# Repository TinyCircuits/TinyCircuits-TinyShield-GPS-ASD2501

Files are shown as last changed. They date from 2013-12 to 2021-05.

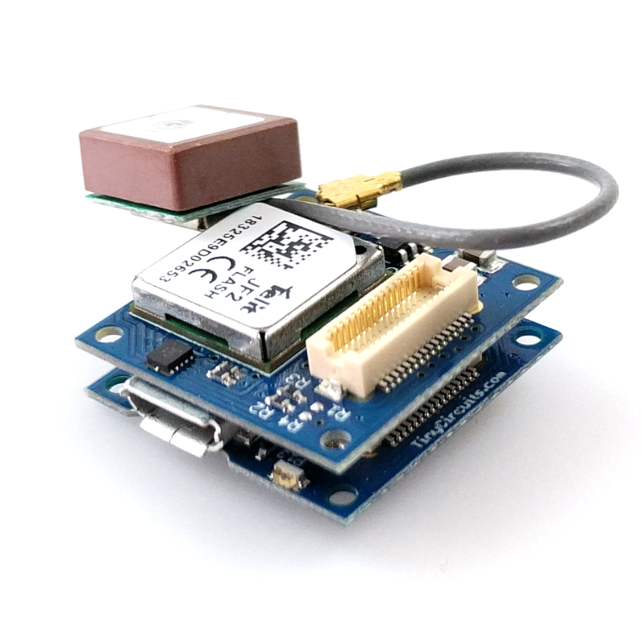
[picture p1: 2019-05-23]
images/ASD2501-R-Tutorial-Image-03.jpg

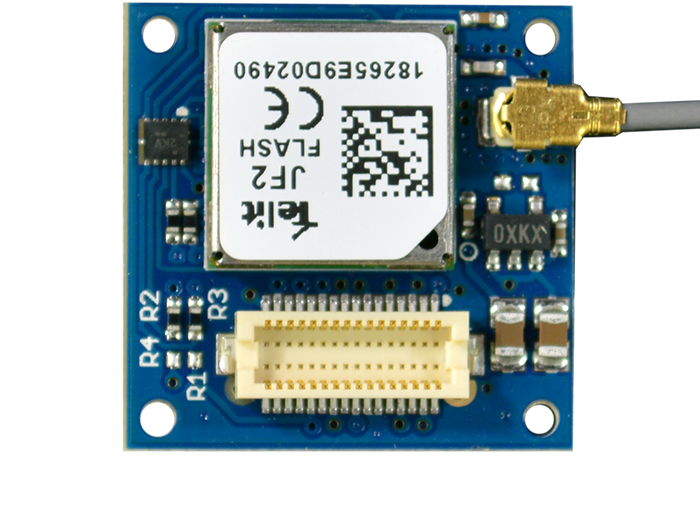
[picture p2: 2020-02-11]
images/ASD2501-R-Tutorial-Image-01.png

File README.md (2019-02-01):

# TinyCircuits TinyShield GPS Board
# ASD2501 Rev4

The design files are located under design_files/ for the TinyCircuits ASD2501 Rev 4 PCB.  This is a TinyShield board that has a GPS module, local power supply, antenna and level shifters to receive GPS data.

Format is in Cadsoft Eagle format - Eagle version 6.2 was used for the original design.

For more infomation on this, check out the product page at TinyCircuits.com:  https://tinycircuits.com/collections/sensors/products/gps-tinyshield

#License:

Design by TinyCircuits.
All design files are released under the Creative Commons Attribution Share-Alike 3.0 License, see the following link for details: http://creativecommons.org/licenses/by-sa/3.0

All text above must be included in any redistribution or derived design

This project uses designs and concepts developed as part of the Arduino project and the LilyPad project.  The TinyCircuits design files themselves (schematics, PCB and libraries) are not directly derived from these works' design files and have been created new, however the concepts and basic architecture behind the TinyDuino and TinyLily products are derived and we thank the hard work of the organizations below for their contributions to open-source hardware:
  
Original Arduino Uno Design by Team Arduino

LilyPad Arduino Design by Leah Buechley and Sparkfun Electronics

Please support the open-source hardware community

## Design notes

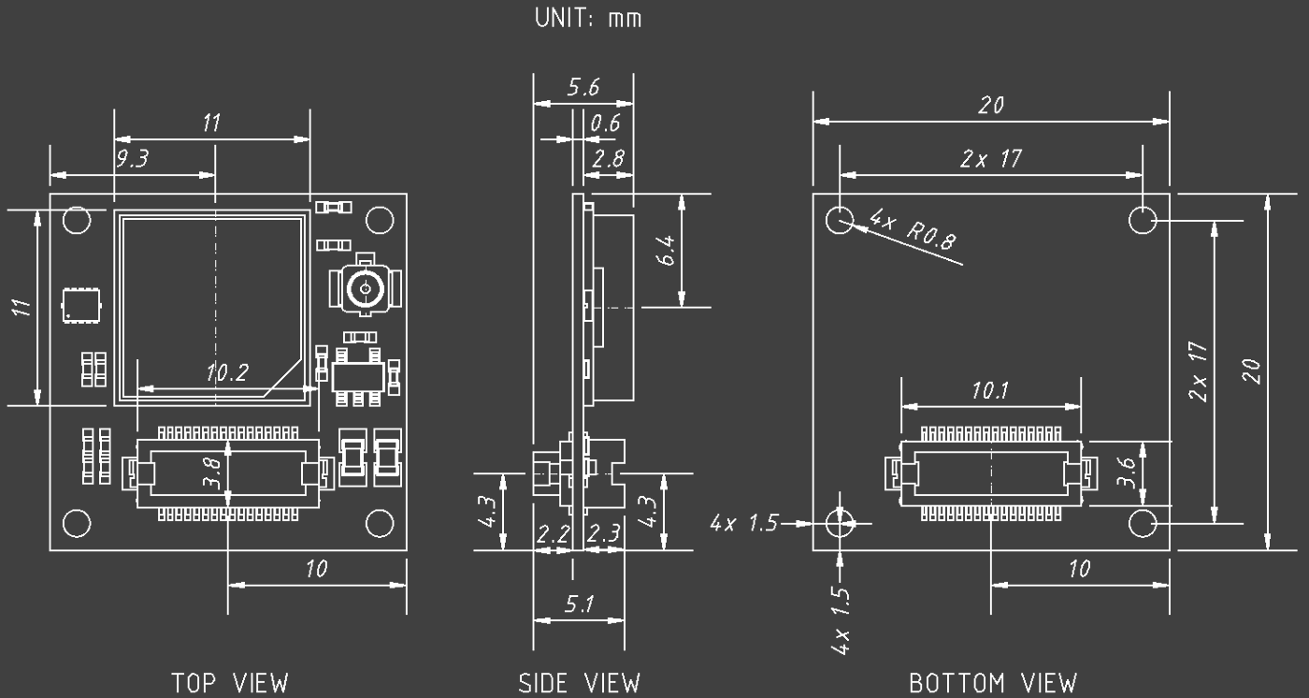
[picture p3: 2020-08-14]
cad/TinyShield_GPS_ASD2501_REV4-DETAILED_DRAWING_COMPACT-PNG.png

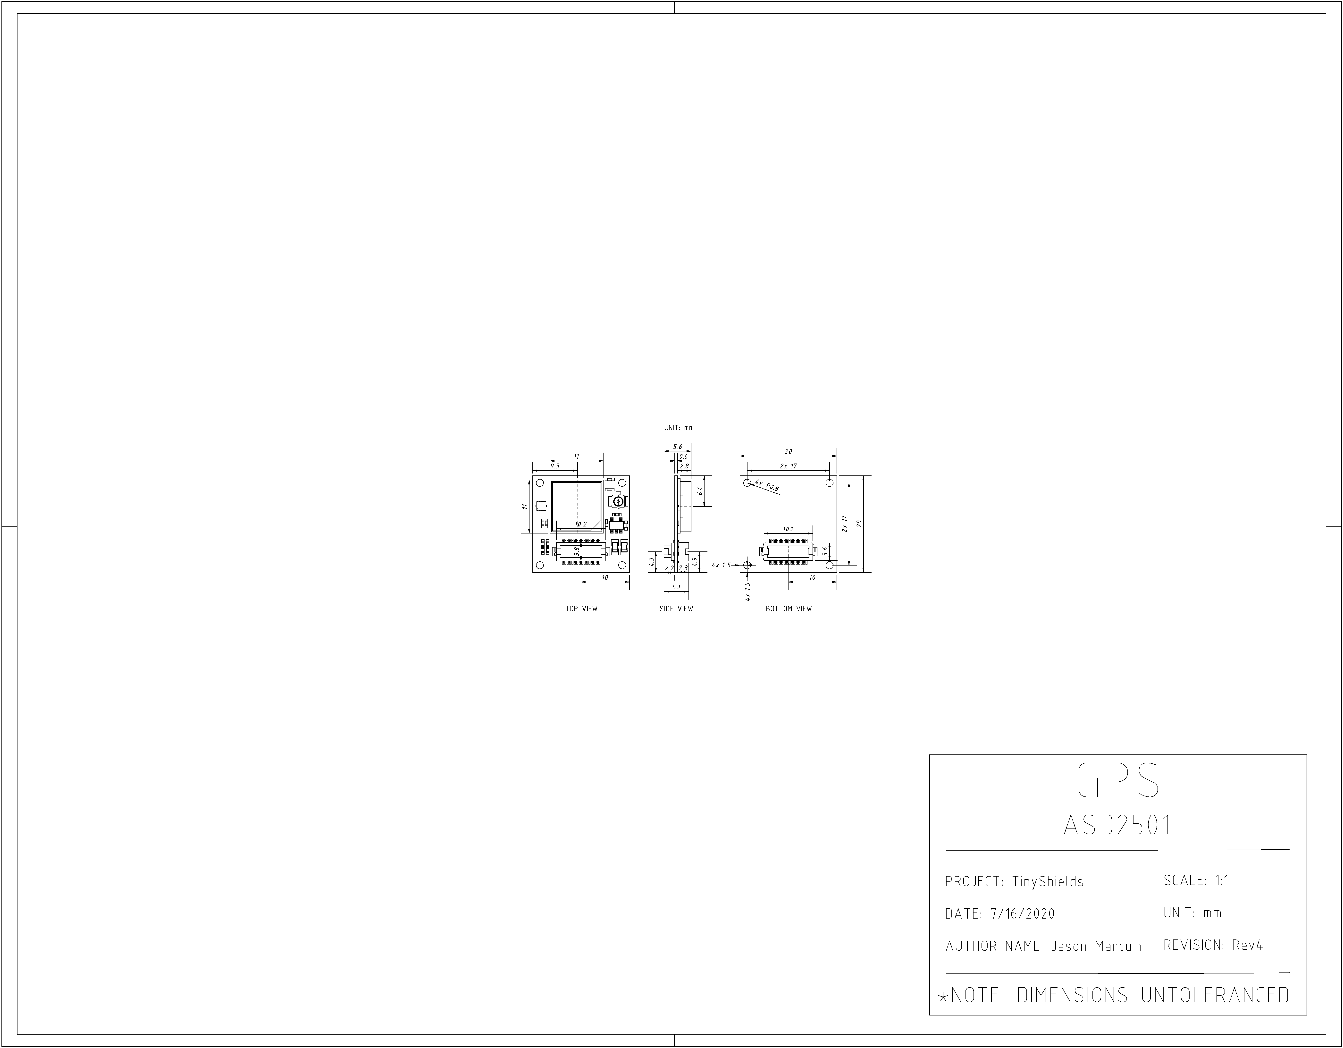
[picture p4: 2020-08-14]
cad/TinyShield_GPS_ASD2501_REV4-DETAILED_DRAWING-PNG.png

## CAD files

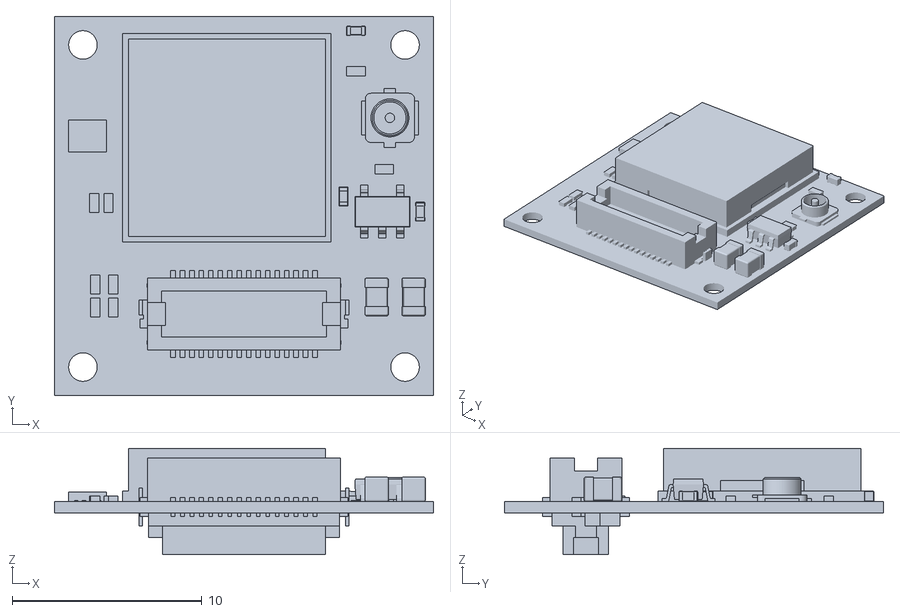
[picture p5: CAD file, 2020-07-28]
cad/TinyShield_GPS_ASD2501_REV4-STL.stl
20.0 x 20.0 x 5.60

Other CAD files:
cad/TinyShield_GPS_ASD2501_REV4-DETAILED_DRAWING-DXF.dxf

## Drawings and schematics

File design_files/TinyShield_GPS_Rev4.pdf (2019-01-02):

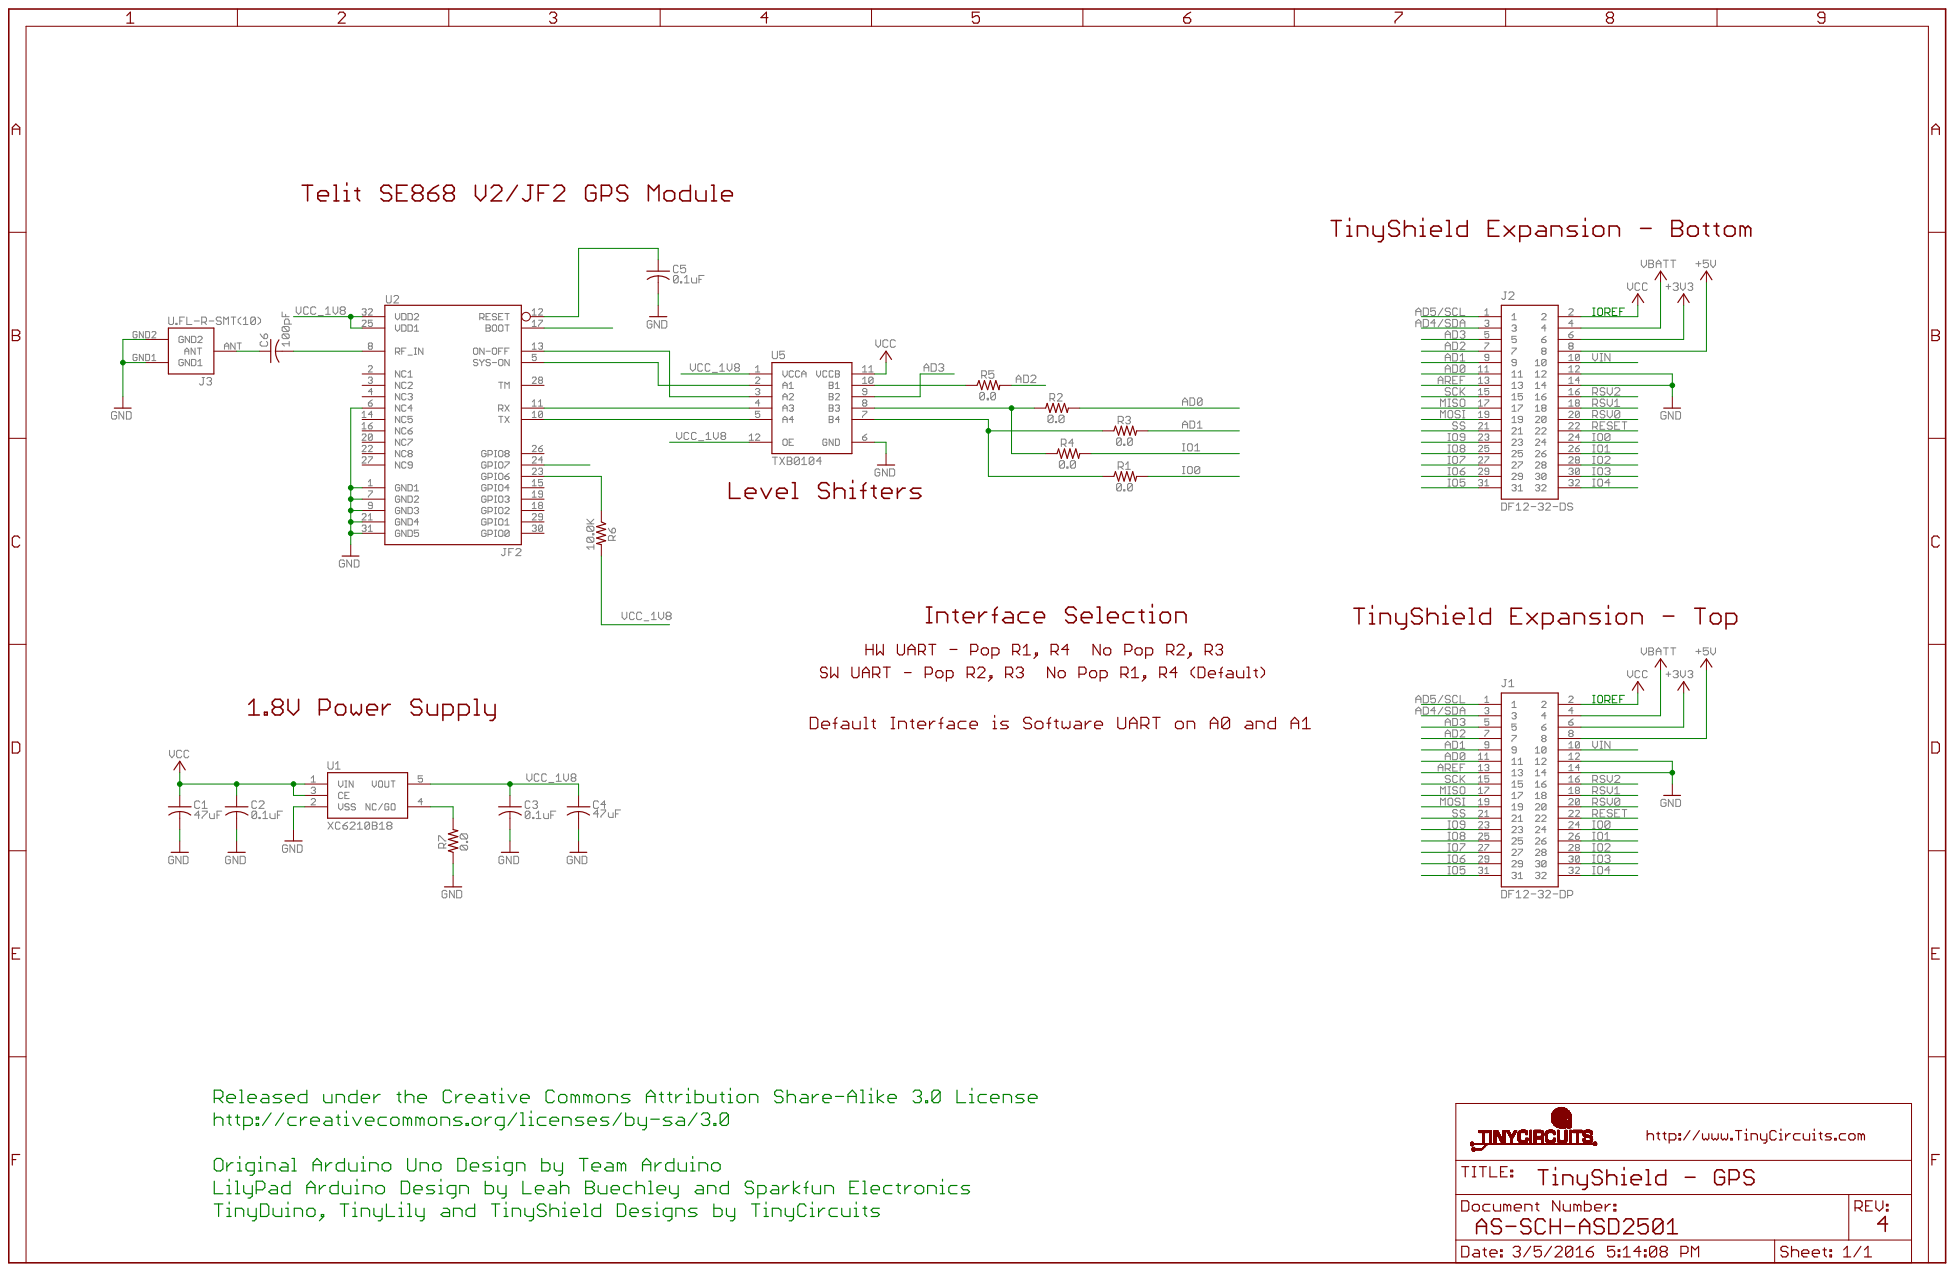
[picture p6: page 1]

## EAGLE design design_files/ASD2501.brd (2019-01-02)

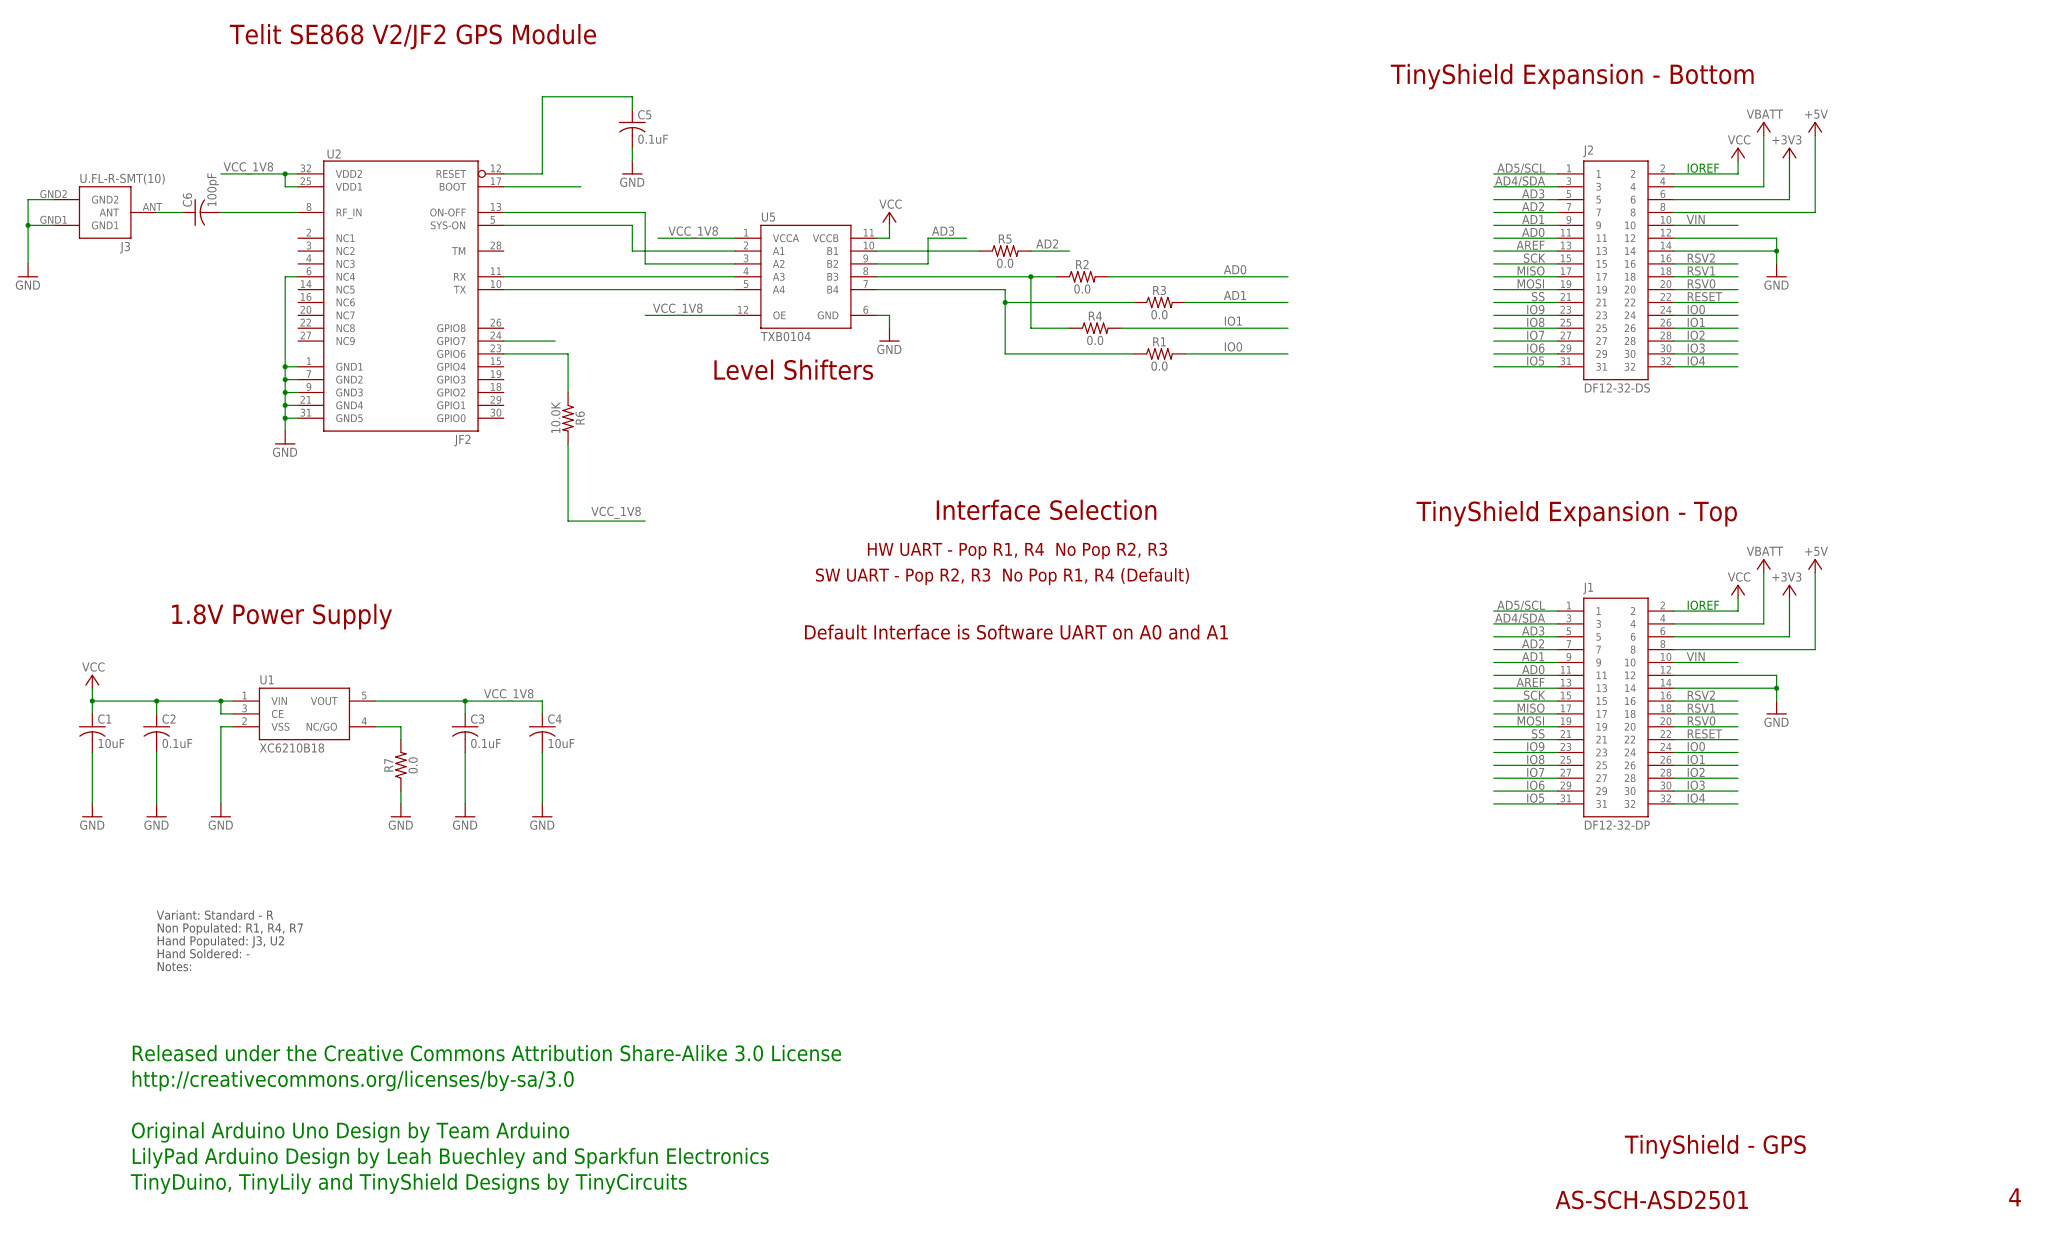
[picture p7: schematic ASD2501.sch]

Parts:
C1, C4: 10uF; C0805; PARTNO AS-ITM-00045
C2, C3, C5: 0.1uF; C0402; PARTNO AS-ITM-00008
C6: 100pF; 0402; PARTNO AS-ITM-00148
J1: DF12-32-DP; PARTNO AS-ITM-00015
J2: DF12-32-DS; PARTNO AS-ITM-00012
J3: U.FL-R-SMT(10)
R1, R2, R3, R4: 0.0; 0402
R5, R7: 0.0; 0402; PARTNO AS-ITM-00076
R6: 10.0K; 0402
U1: XC6210B18; SOT-25; PARTNO AS-ITM-00075
U2: JF2
U5: TXB0104; UQFN-12

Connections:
+3V3: J1.6, J2.6
+5V: J1.8, J2.8
AD0: J1.11, J2.11, R2.2
AD1: J1.9, J2.9, R3.2
AD2: J1.7, J2.7, R5.2
AD3: J1.5, J2.5, U5.9 (B2)
AD4/SDA: J1.3, J2.3
AD5/SCL: J1.1, J2.1
AREF: J1.13, J2.13
GND: C1.2, C2.2, C3.2, C4.2, C5.2, J1.12, J1.14, J2.12, J2.14, J3.GND1, J3.GND2, R7.1, U1.2 (VSS), U2.1 (GND1), U2.6 (NC4), U2.7 (GND2), U2.9 (GND3), U2.21 (GND4), U2.31 (GND5), U5.6 (GND)
IO0: J1.24, J2.24, R1.2
IO1: J1.26, J2.26, R4.2
IO2: J1.28, J2.28
IO3: J1.30, J2.30
IO4: J1.32, J2.32
IO5: J1.31, J2.31
IO6: J1.29, J2.29
IO7: J1.27, J2.27
IO8: J1.25, J2.25
IO9: J1.23, J2.23
MISO: J1.17, J2.17
MOSI: J1.19, J2.19
unnamed: C6.1, J3.ANT
unnamed: R2.1, R4.1, U5.8 (B3)
unnamed: R1.1, R3.1, U5.7 (B4)
unnamed: U2.11 (RX), U5.4 (A3)
unnamed: R6.1, U2.23 (GPIO6)
unnamed: R7.2, U1.4 (NC/GO)
unnamed: U2.10 (TX), U5.5 (A4)
unnamed: C5.1, U2.12 (RESET)
unnamed: C6.2, U2.8 (RF_IN)
unnamed: U2.13 (ON-OFF), U5.3 (A2)
unnamed: U2.5 (SYS-ON), U5.2 (A1)
unnamed: R5.1, U5.10 (B1)
RESET: J1.22, J2.22
RSV0: J1.20, J2.20
RSV1: J1.18, J2.18
RSV2: J1.16, J2.16
SCK: J1.15, J2.15
SS: J1.21, J2.21
VBATT: J1.4, J2.4
VCC: C1.1, C2.1, J1.2, J2.2, U1.1 (VIN), U1.3 (CE), U5.11 (VCCB)
VCC_1V8: C3.1, C4.1, R6.2, U1.5 (VOUT), U2.25 (VDD1), U2.32 (VDD2), U5.1 (VCCA), U5.12 (OE)
VIN: J1.10, J2.10

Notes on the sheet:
TinyShield Expansion - Bottom
TinyShield - GPS
AS-SCH-ASD2501
TinyShield Expansion - Top
IOREF
Released under the Creative Commons Attribution Share-Alike 3.0 License
http://creativecommons.org/licenses/by-sa/3.0
LilyPad Arduino Design by Leah Buechley and Sparkfun Electronics
TinyDuino, TinyLily and TinyShield Designs by TinyCircuits
Original Arduino Uno Design by Team Arduino
1.8V Power Supply
Telit SE868 V2/JF2 GPS Module
Level Shifters
Interface Selection
HW UART - Pop R1, R4 No Pop R2, R3
Default Interface is Software UART on A0 and A1
SW UART - Pop R2, R3 No Pop R1, R4 (Default)
Non Populated: R1, R4, R7
Hand Populated: J3, U2
Hand Soldered: -
Notes:
Variant: Standard - R

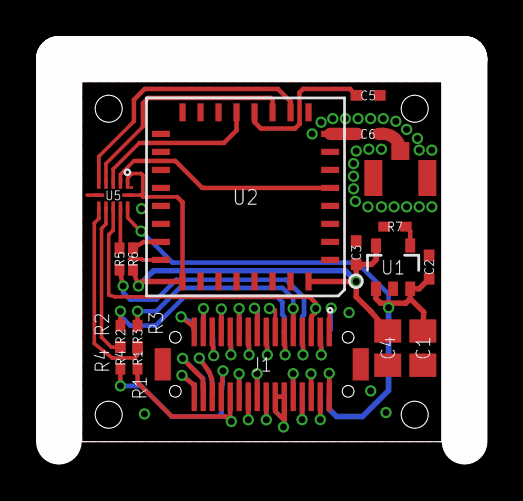
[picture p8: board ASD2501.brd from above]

Board: 2 copper layers, 20.0 x 20.0 mm, 20 parts (1 on the bottom side), 44 nets.

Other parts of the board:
U$1: DOCFIELD-TINYCIRCUITS-PCB

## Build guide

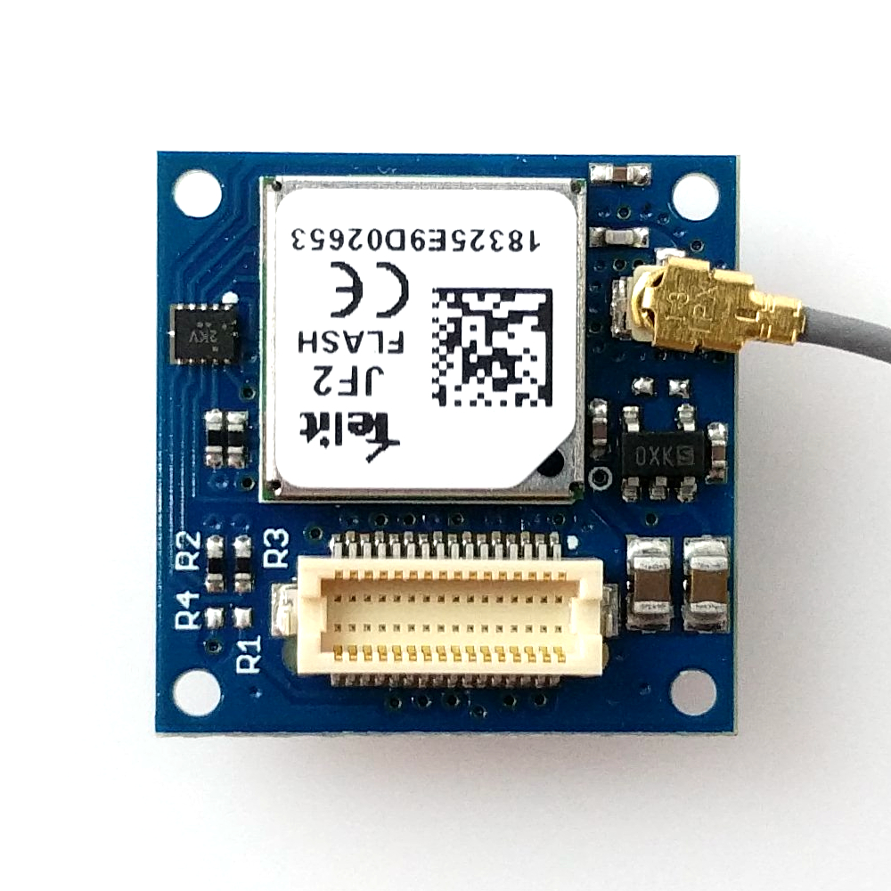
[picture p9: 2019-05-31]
images/ASD2501-R-Tutorial-Image-01.jpg

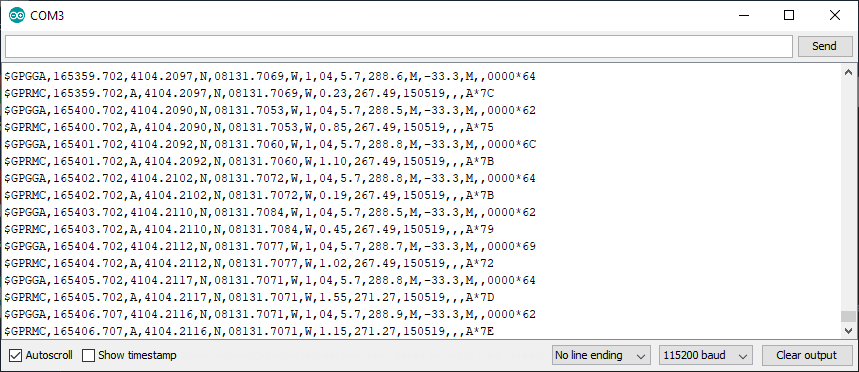
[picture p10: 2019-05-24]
images/ASD2501-Tutorial-Image-05.png

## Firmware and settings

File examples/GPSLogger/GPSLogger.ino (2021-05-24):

/*
  TinyCircuits GPS TinyShield Logging Example
  
  This example logs GPS NMEA sentences to an SD card. If it doesn't detect an SD
  card at startup, it will output data to the Serial Monitor.
  With the Telit SE868 V2 module with Glonass support, some messages come through
  as GN** sentences instead of GP**. These are changed back to GP** before logging
  so that they don't cause problems with programs like Google Earth.
  
  If you see bad data:
  - Make sure the baud rate in the Serial Monitor is the same you see set in the below 
    program for the SerialMonitorInterface - 115200
  - Some GPS modules shipped before 2018 shipped with 4800 baud instead of 9600. Try changing 
    this value in the top of the GPS.h file.

  Written 10 July 2018 By Ben Rose
  Modified 07 January 2019 By Hunter Hykes
   - This update added SoftwareSerialZero files modified for SAMD21 based boards like
     the TinyScreen+, TinyZero or Arduino Zero.
  Modified May 2021 to clarify comments

  https://TinyCircuits.com
*/

#include "GPS.h"
#include <SD.h>

#if defined (ARDUINO_ARCH_AVR)
#define SerialMonitorInterface Serial
#include <SoftwareSerial.h>
#elif defined(ARDUINO_ARCH_SAMD)
#define SerialMonitorInterface SerialUSB
#include "SoftwareSerialZero.h"
#endif

const int chipSelect = 10;
int cardPresent;

// The GPS connection is attached with a software serial port
SoftwareSerial softSerial(GPS_RXPin, GPS_TXPin);

#define Gps_serial softSerial

void setup()
{
  Gps_serial.begin(GPSBaud);
  SerialMonitorInterface.begin(115200);
  while (!SerialMonitorInterface && millis() < 5000); //On TinyScreen+, this will wait until the Serial Monitor is opened or until 5 seconds has passed

  gpsInitPins();
  delay(100);
  SerialMonitorInterface.print("Attempting to wake GPS module.. ");
  gpsOn();
  SerialMonitorInterface.println("done.");
  delay(200);

  //Enable and set interval or disable, per NMEA sentence type
  Gps_serial.print(gpsConfig(NMEA_GGA_SENTENCE, 1));
  Gps_serial.print(gpsConfig(NMEA_GLL_SENTENCE, 0));
  Gps_serial.print(gpsConfig(NMEA_GSA_SENTENCE, 0));
  Gps_serial.print(gpsConfig(NMEA_GSV_SENTENCE, 0));
  Gps_serial.print(gpsConfig(NMEA_RMC_SENTENCE, 1));
  Gps_serial.print(gpsConfig(NMEA_VTG_SENTENCE, 0));
  Gps_serial.print(gpsConfig(NMEA_GNS_SENTENCE, 0));

  SerialMonitorInterface.print("Initializing SD card...");

  // see if the card is present and can be initialized:
  if (SD.begin(chipSelect)) {
    SerialMonitorInterface.println("card initialized.");
    cardPresent = true;
  } else {
    SerialMonitorInterface.println("Card failed, or not present- continuing with serial output");
    cardPresent = false;
  }
}

void loop() {
  handleGPS();
}

char waitForCharacter() {
  while (!Gps_serial.available());
  return Gps_serial.read();
}

void handleGPS() {
  while (Gps_serial.read() != '$') {
    if(!Gps_serial.available()){
      return;
    }
  }
  int counter = 1;
  char c = 0;
  char buffer[100];
  buffer[0] = '$';
  c = waitForCharacter();
  while (c != '*') {
    buffer[counter++] = c;
    if(c=='$'){//new start
      counter=1;
    }
    c = waitForCharacter();
  }
  buffer[counter++] = c;
  buffer[counter++] = waitForCharacter();
  buffer[counter++] = waitForCharacter();
  buffer[counter++] = '\r';
  buffer[counter++] = '\n';
  buffer[counter] = '\0';

  buffer[1] = 'G';
  buffer[2] = 'P';

  gpsDoChecksum(buffer);

  if (cardPresent) {
    File dataFile = SD.open("gps.txt", FILE_WRITE);
    // if the file is available, write to it:
    if (dataFile) {
      dataFile.write(buffer, counter);
      dataFile.close();
    } else {
      SerialMonitorInterface.println("error opening gps.txt");
      cardPresent = false;
    }
  } else {
    SerialMonitorInterface.print((char *)buffer);
  }
}

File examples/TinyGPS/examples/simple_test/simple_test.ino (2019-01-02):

/* This sample code demonstrates the normal use of a TinyGPS object,
 * customised for the TinyCircuits GPS module.
*/


#include <TinyGPS.h>
#include "GPS.h"

TinyGPS gps;
char buf[32];

#if defined (ARDUINO_ARCH_AVR)
#define SerialMonitorInterface Serial
#include <SoftwareSerial.h>
#elif defined(ARDUINO_ARCH_SAMD)
#define SerialMonitorInterface SerialUSB
#include "SoftwareSerialZero.h"
#endif

// The GPS connection is attached with a software serial port
SoftwareSerial ss(GPS_RXPin, GPS_TXPin);


void setup()
{
  SerialMonitorInterface.begin(115200);
  ss.begin(GPSBaud);
  while (!SerialMonitorInterface && millis() < 5000); //On TinyScreen+/SAMD21 platform, this will wait until the Serial Monitor is opened or until 5 seconds has passed
  
  SerialMonitorInterface.print("Simple TinyGPS library v. "); SerialMonitorInterface.println(TinyGPS::library_version());
  SerialMonitorInterface.println("by Mikal Hart");
  SerialMonitorInterface.println();
  
  gpsInitPins();
  delay(100);
  SerialMonitorInterface.print("Attempting to wake GPS module.. ");
  gpsOn();
  SerialMonitorInterface.println("done.");
  delay(100);
  while (ss.available())ss.read();
}

void loop()
{
  bool newData = false;
  unsigned long chars;
  unsigned short sentences, failed;

  // For one second we parse GPS data and report some key values
  for (unsigned long start = millis(); millis() - start < 1000;)
  {
    while (ss.available())
    {
      char c = ss.read();
      // SerialMonitorInterface.write(c); // uncomment this line if you want to see the GPS data flowing
      if (gps.encode(c)) // Did a new valid sentence come in?
        newData = true;
    }
  }

  unsigned long age;
  if (newData)
  {
    float flat, flon;
    gps.f_get_position(&flat, &flon, &age);
    SerialMonitorInterface.print("LAT=");
    SerialMonitorInterface.print(flat == TinyGPS::GPS_INVALID_F_ANGLE ? 0.0 : flat, 6);
    SerialMonitorInterface.print(" LON=");
    SerialMonitorInterface.print(flon == TinyGPS::GPS_INVALID_F_ANGLE ? 0.0 : flon, 6);
    SerialMonitorInterface.print(" SAT=");
    SerialMonitorInterface.print(gps.satellites() == TinyGPS::GPS_INVALID_SATELLITES ? 0 : gps.satellites());
    SerialMonitorInterface.print(" PREC=");
    SerialMonitorInterface.print(gps.hdop() == TinyGPS::GPS_INVALID_HDOP ? 0 : gps.hdop());
    //GPS mode
    SerialMonitorInterface.print(" Constellations=");
    SerialMonitorInterface.print(flat == TinyGPS::GPS_INVALID_F_ANGLE ? 0 : gps.constellations());
  }

  //satellites in view
  uint32_t* satz = gps.trackedSatellites();
  uint8_t sat_count = 0;
  for(int i=0;i<24;i++)
  {
    if(satz[i] != 0)    //exclude zero SNR sats
    {
      sat_count++;
      byte strength = (satz[i]&0xFF)>>1;
      byte prn = satz[i]>>8;
      sprintf(buf, "PRN %d: ", prn);
      SerialMonitorInterface.print(buf);
      SerialMonitorInterface.print(strength);
      SerialMonitorInterface.println("dB");
    }
  }
  
  //date time
  int year;
  uint8_t month, day, hour, minutes, second, hundredths;
  gps.crack_datetime(&year, &month, &day, &hour, &minutes, &second, &hundredths, &age);
  sprintf(buf,"GPS time: %d/%02d/%02d %02d:%02d:%02d", year, month, day, hour, minutes, second);
  SerialMonitorInterface.println(buf);

  gps.stats(&chars, &sentences, &failed);
  SerialMonitorInterface.print(" CHARS=");
  SerialMonitorInterface.print(chars);
  SerialMonitorInterface.print(" SENTENCES=");
  SerialMonitorInterface.print(sentences);
  SerialMonitorInterface.print(" CSUM ERR=");
  SerialMonitorInterface.println(failed);
  if (chars == 0)
    SerialMonitorInterface.println("** No characters received from GPS: check wiring **");
}

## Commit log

2013-12-26 Updated antenna ref des
    [ASD2501.brd, ASD2501.sch]
2019-01-02 update format
    [ASD2501.brd, ASD2501.sch]
2020-07-28 Add CAD data
    [TinyShield_GPS_ASD2501_REV4-DETAILED_DRAWING-DXF.dxf, TinyShield_GPS_ASD2501_REV4-STL.stl]
2020-08-14 Update CAD drawing
    [TinyShield_GPS_ASD2501_REV4-DETAILED_DRAWING-DXF.dxf]
